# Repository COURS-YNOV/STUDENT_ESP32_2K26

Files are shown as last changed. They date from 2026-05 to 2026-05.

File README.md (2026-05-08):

# Projet ESP32 – Conception Électronique 2K26

## Contexte

Dans le cadre du projet de conception électronique, vous devez réaliser une carte de développement basée sur un **ESP32-PICO-D4**.

Le projet s’appuie sur un cahier des charges client fictif : **Ventec Systems**, entreprise spécialisée dans les AGV industriels. La carte doit permettre le monitoring d’un robot alimenté par une batterie 36V, avec mesure de courant, surveillance thermique, communication BLE et reprogrammation terrain.

Le cahier des charges complet ainsi que l’énoncé du projet sont disponibles dans le dossier :
```text
10_doc_ext/
```
Le projet Altium est situé dans :
```text
30_src/
```
Fichier projet principal :
```text
ESP32_Projet.PrjPcb
```

## Objectif du projet

Chaque équipe doit réaliser :

une analyse fonctionnelle du système ;
la sélection et l’étude des composants ;
la schématique de la carte ;
le routage PCB ;
les fichiers de fabrication ;
un rapport expliquant les choix techniques.

La carte doit respecter une taille maximale de :
```text
70 mm x 50 mm
```
Tous les composants doivent être placés uniquement sur la face TOP du PCB.

## Organisation des équipes

Le projet est réalisé en 5 équipes.

Chaque équipe doit travailler sur sa propre branche Git.

Format obligatoire du nom de branche :
```text
Equipe_1
Equipe_2
Equipe_3
Equipe_4
Equipe_5
```

## Structure du dépôt
```text
/10_doc_ext/
    CDC-VENTEC_SYSTEMS.pdf
    Enonce-Projet2k26_ESP32.pdf

/30_src/
    Projet Altium
    Librairies SCH_Lib / PCB_Lib
    PCB vierge
    Schématique vide
```

## Projet Altium

### Composants principaux

Les composants principaux imposés sont :

Microcontrôleur : ESP32-PICO-D4
Driver USB-UART : CP2104-F03-GM
Connecteur USB-C : USB4085-GF-A
Capteur de courant : INA237AIDGST

Des résistances, condensateurs, LEDs, connecteurs Grove / MikroBus, antenne, boutons reset / boot et autres composants seront également nécessaires.

### Contraintes principales

#### Alimentation

La carte doit pouvoir être alimentée par trois sources :

USB-C : 5V
BT : 3.7V à 10V
HT : jusqu’à 36V

La priorité d’alimentation doit être :
```text
USB > BT > HT
```
La gestion de priorité doit être réalisée matériellement, sans dépendre du firmware.

#### Mesures

La carte doit permettre :
- la mesure du courant sur la batterie 36V
- la surveillance de températures PCB
- la mesure de température ambiante
- l’ajout de capteurs via Grove / MikroBus

#### Communication

La carte doit intégrer :
- communication BLE
- USB-C pour reprogrammation et extraction des logs
- protection des lignes USB
- gestion de l’antenne BLE avec adaptation du plan de masse

#### IHM

La carte doit intégrer :
- LED verte de fonctionnement normal
- LED rouge d’alarme
- buzzer piloté par l’ESP32
- boutons reset et boot accessibles

## Règles de conception imposées
### Schématique

- Schématique en mils
- Titre, révision et nom du dessinateur attendus
- Paires différentielles clairement indiquées

### PCB

- PCB en mm
- Taille maximale : 70 mm x 50 mm
- Aucun composant sur la face Bottom
- Pas d’angles droits sur les pistes
- Arrivée des pistes au centre des pads
- Plan de masse obligatoire
- Plan d’alimentation recommandé
- Vias : pastille 0.85 mm, perçage 0.35 mm
- Sérigraphie : largeur 0.15 mm
- Impédance 90 Ω sur la ligne de reprogrammation UART
- Impédance 50 Ω sur la ligne RF
- Adaptation du plan de masse autour de l’antenne BLE

## Barème : Update en cours

## Workflow Git
1. Cloner le dépôt
```bash
git clone https://github.com/COURS-YNOV/STUDENT_ESP32_2K26.git
cd STUDENT_ESP32_2K26
```
2. Créer la branche de votre équipe
```bash
git checkout -b Equipe_X
```
Exemple : 
```bash
git checkout -b Equipe_1
```

3. Travailler uniquement sur votre branche

Ne travaillez jamais directement sur main.

4. Ajouter vos fichiers
```bash
git add .
```

5. Faire un commit
```bash
git commit -m "avancement projet ESP32"
```

6. Push les modifications sur votre branch
```bash
git push Equipe_X
```
## Rapport attendu

Le rapport doit contenir :
- Les analyses fonctionnelles (AF 1 & AF 2)
- L’explication des différents blocs schématiques
- Les choix techniques réalisés
- Deux problèmes rencontrés pendant le projet ainsi que leurs solutions
- Les captures ou éléments utiles à la compréhension du projet

Le rapport doit être rendu au format PDF.

## Conseils
- Lire entièrement le cahier des charges avant de commencer
- Répartir les tâches dans l’équipe
- Vérifier régulièrement le DRC
- Commiter souvent
- Générer les Gerbers même si le projet n’est pas terminé
- Utiliser la documentation et les tutoriels vus en cours

# Bon courage à tous !

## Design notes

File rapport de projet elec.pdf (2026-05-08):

Rapport de projet CDC – Ventec Systems Groupe KIMG
Irwin Ticon – Marine Jacolot – Guilhem Raffanel – Killian Guillemot

## Table des matières

# 1.Analyse fonctionnelle de niveau 1

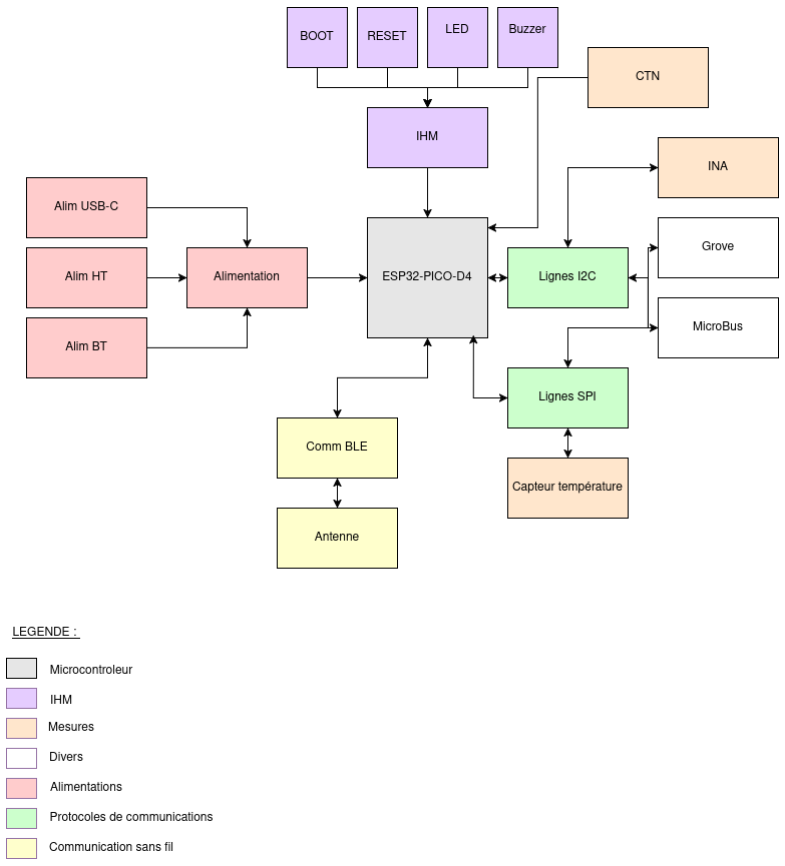
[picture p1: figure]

# 2.Analyse fonctionnelle de niveau 2

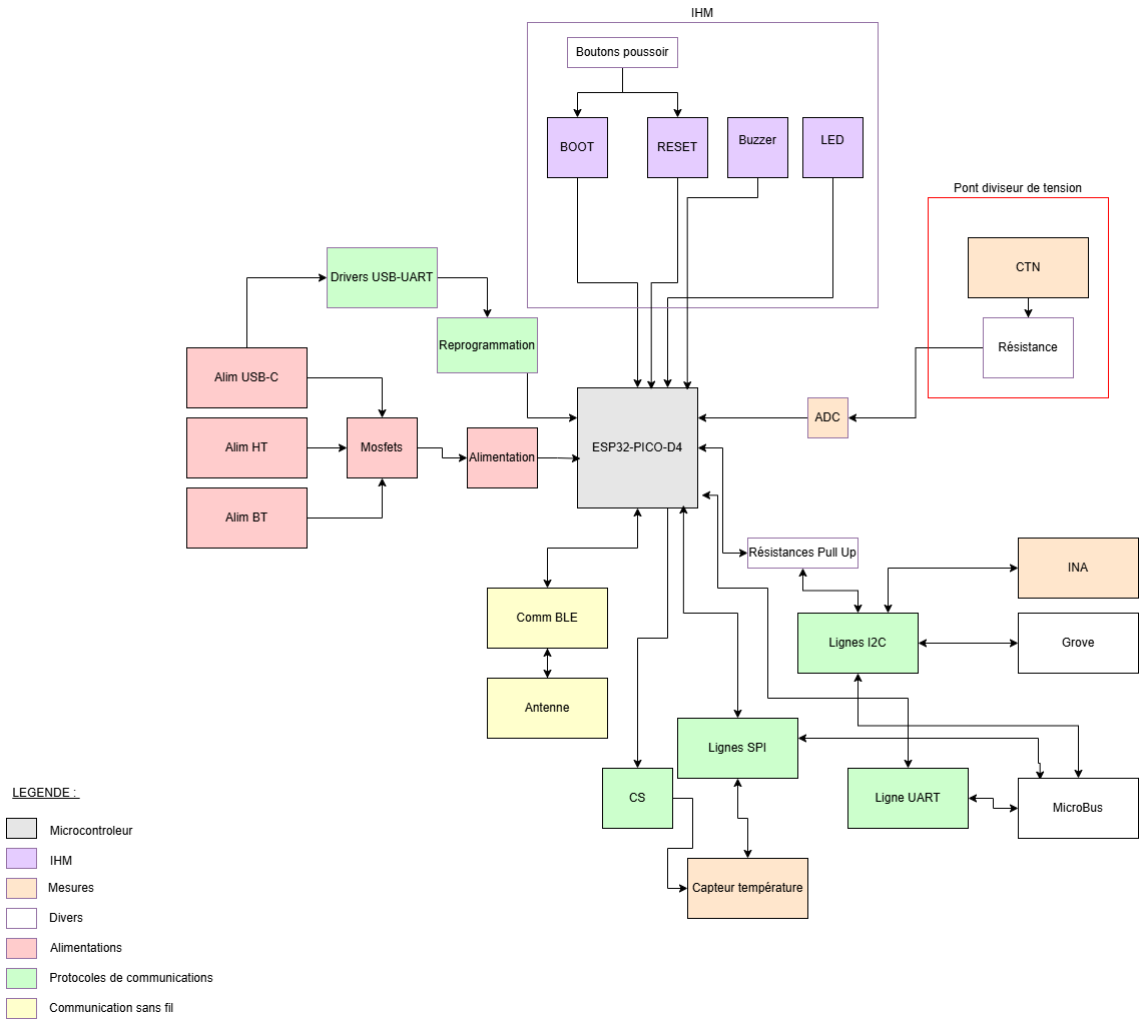
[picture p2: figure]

# 3.Schématiques

## a. Alimentations

### i. Alimentation HT

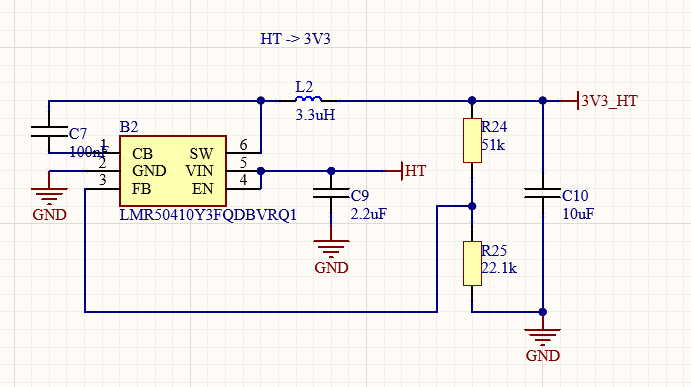
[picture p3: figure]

Le convertisseur LMR accepte des tensions d'entrée comprises entre -0,3 V et 38 V sur VIN, et entre 0 V et VIN+0,3 V sur EN, ce qui satisfait les exigences de notre application (plage 27 V–36 V). Le schéma a été conçu conformément à la configuration typique recommandée par le fabricant. Les résistances de polarisation R24 et R25 ont été dimensionnées selon les paramètres spécifiés dans la fiche technique du composant.

### ii. Alimentation 5V USB

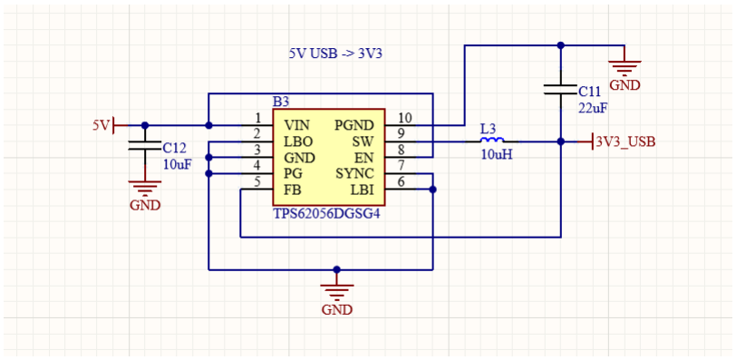
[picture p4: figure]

Le régulateur de tension TPS accepte des tensions d'entrée comprises entre 2,7 V et 10 V, ce qui satisfait notre besoin d'une tension de sortie stable de 5 V. Le schéma a été conçu
conformément à la configuration typique du fabricant.

Alimentation Basse Tension

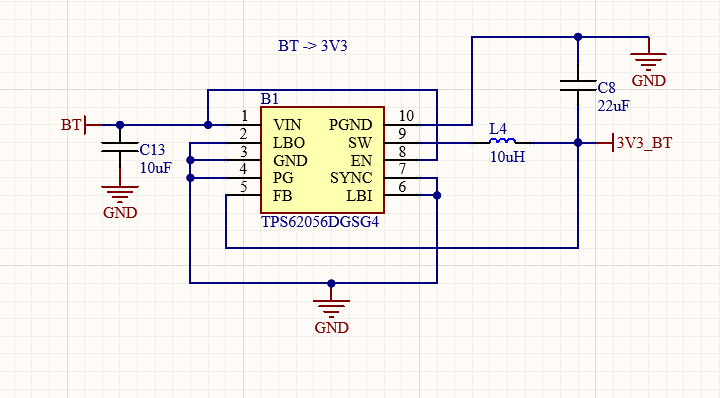
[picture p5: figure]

Le régulateur de tension TPS accepte des tensions d'entrée comprises entre 2,7 V et 10 V, couvrant ainsi la plage d'alimentation variable requise de 3,7 V à 10 V. Le schéma a été conçu conformément à la configuration typique recommandée par le fabricant.

### iii. Circuit de gestion de priorité d’alimentation

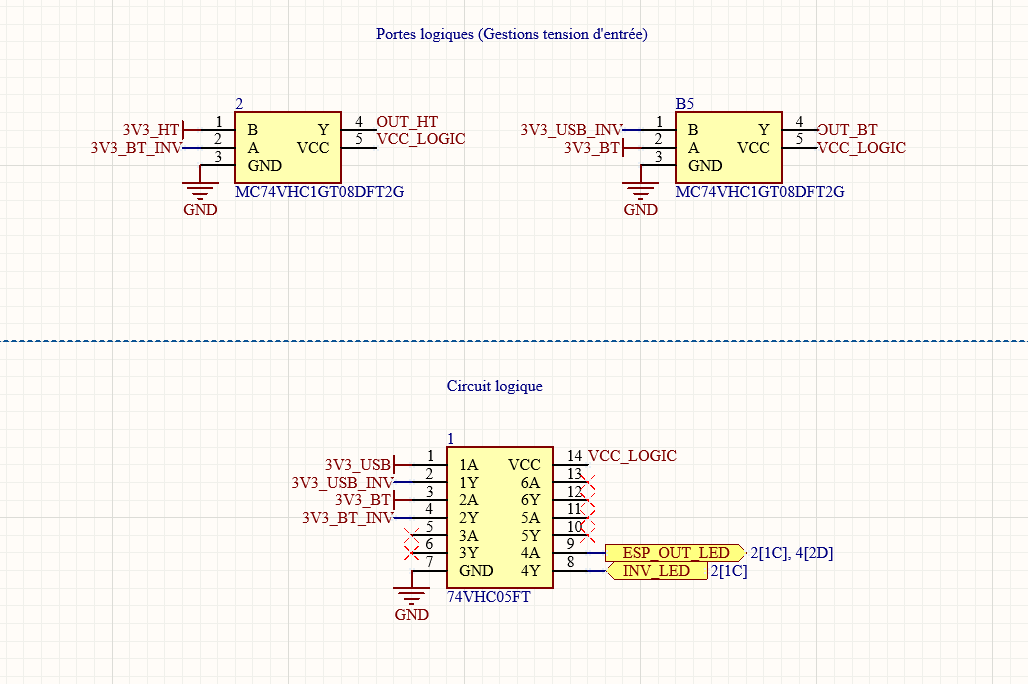
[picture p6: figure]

Le MC74 est une porte logique AND alimentée par VCC_LOGIC (3,3 V, provenant des régulateurs décrits précédemment). En sortie, il restitue la tension VIN lorsque les conditions logiques d'entrée sont satisfaites.

Le 74VH est un circuit intégré contenant plusieurs portes logiques NOT, également alimenté par VCC_LOGIC (3,3 V). Il fournit en sortie la tension VIN inversée selon la logique appliquée en entrée.

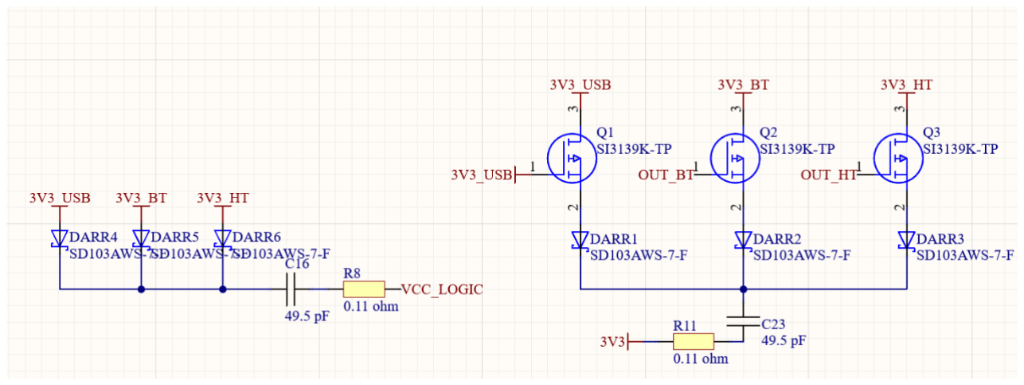
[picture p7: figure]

Des transistors MOSFET canal P ont été sélectionnés comme interrupteurs commandés par les signaux logiques. La section gauche du schéma assure l'alimentation des portes logiques, avec protection par diodes. L'ensemble intègre des condensateurs de découplage et des résistances de charge pour garantir la stabilité et les transitions correctes.

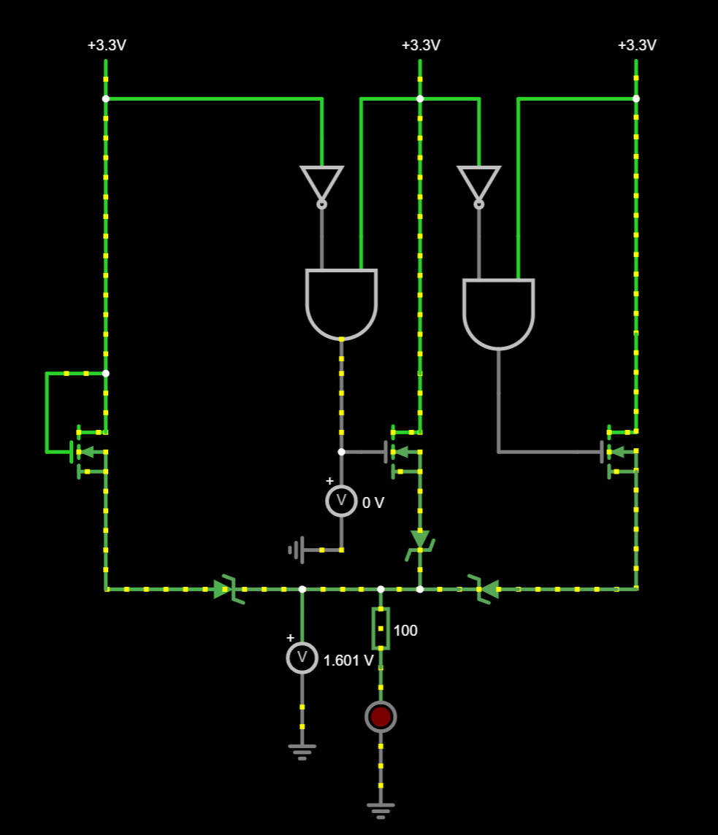
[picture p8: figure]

Le schéma ci-dessus est une simulation sur le logiciel Falstad montrant le montage de gestion de priorité d’alimentation.

## b. IHM

### i. Buzzer

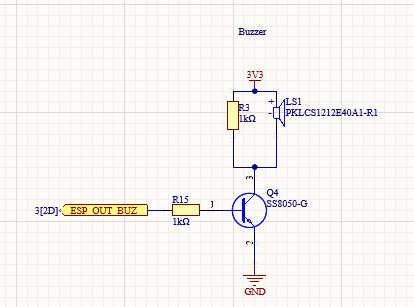
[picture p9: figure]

Choix de composant :
Selon L’EXF-26 nous avons modifié l’usage typique du PKLCS en retirant les portes logiques et en le connectant directement à l’ESP pour nous permettre de piloter le PKLCS depuis l’ESP directement
Ce circuit permet un pilotage fiable d’un buzzer via un pin sortie, en utilisant un transistor comme interface de puissance.
La schématique a été assemblé selon l’usage typique du PKLCS

### ii. LED

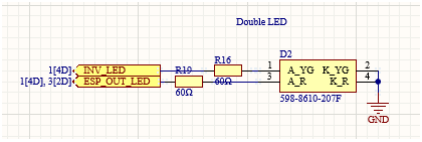
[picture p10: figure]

Choix des composants :
Ce montage permet un pilotage simple et sécurisé d’une double LED à partir d’une sortie microcontrôleur, avec limitation de courant intégrée et possibilité d’indication visuelle
Les signaux de commande INV_LED et ESP_OUT_LED permettent de piloter l’allumage de la LED via un pin sortie du microcontrôleur (ESP) et un inverseur logique.
Les valeurs de 60 Ω ont été choisie pour obtenir un courant maîtrisé dans la LED (~4 à 11 mA selon la couleur)

## c. ESP

### i. Partie A

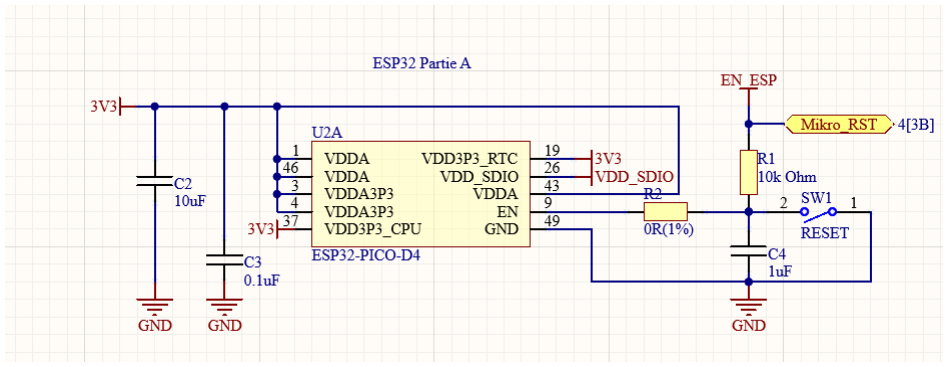
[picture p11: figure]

Choix des composants :
Ce montage correspond à l’alimentation et au démarrage de l’ESP32-PICO-D4. Il permet d’obtenir une alimentation stable en 3V3 tout en assurant un reset correct du microcontrôleur. Les condensateurs C2 et C3 ont été placés en découplage sur l’alimentation afin de filtrer les parasites et de stabiliser la tension fournie à l’ESP32.
La résistance R1 maintient la ligne EN_ESP à l’état haut en fonctionnement normal. Elle joue donc le rôle de pull-up sur l’entrée de reset.
Le bouton SW1 permet de forcer un RESET manuel du microcontrôleur en mettant la ligne de commande à la masse lorsqu’il est actionné.
Le condensateur C4 améliore la mise sous tension et le comportement du reset en filtrant les variations trop rapides sur la ligne EN.
La résistance R2 sert de liaison directe entre la broche EN de l’ESP32 et le signal de commande, tout en offrant une solution simple de modification ou d’adaptation du circuit si nécessaire. L’ensemble du schéma respecte ainsi une structure classique de mise sous tension et de réinitialisation pour un ESP32, avec une alimentation filtrée et un circuit de reset fiable.

### ii. Partie B

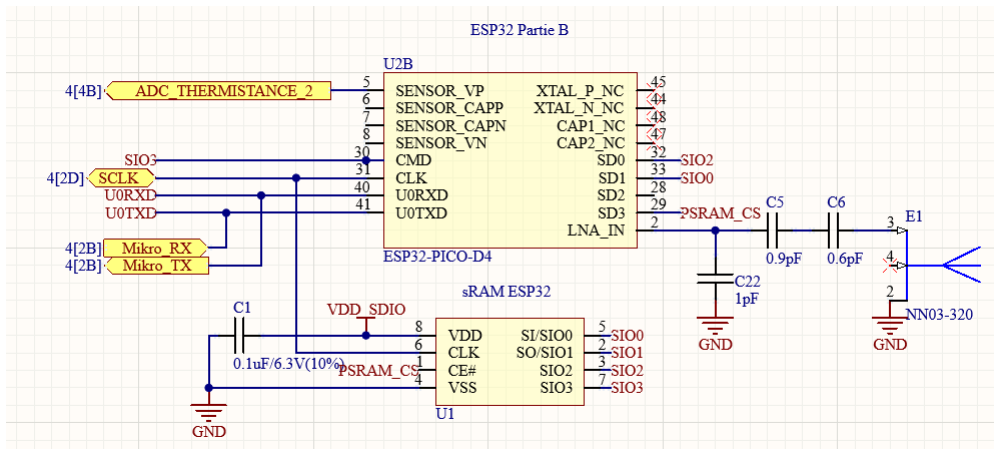
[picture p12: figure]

Choix des composants :
Ce montage correspond à l'interface mémoire et RF de l'ESP32-PICO-D4. Il étend la capacité mémoire du microcontrôleur et assure une connexion radio fiable.
Le condensateur C1 est placé en découplage sur le rail VDD_SDIO. Il filtre les parasites et stabilise la tension fournie à la SRAM.
La mémoire U1 est une SRAM externe connectée à l'ESP32 via un bus SPI quad. La broche CE# est pilotée par le signal PSRAM_CS pour activer ou désactiver la communication avec la mémoire. Elle permet d'augmenter la mémoire disponible pour l'exécution du programme. Les condensateurs C5, C6 et C22 forment un réseau d'adaptation d'impédance entre la sortie RF de l'ESP32 et l'antenne E1. Leurs valeurs de 0,9 pF, 0,6 pF et 1 pF ont été choisies pour minimiser les pertes du signal radio.
L'antenne E1 est une antenne compacte de type chip antenna. Elle a été choisie pour son encombrement réduit et ses bonnes performances sur la bande Wi-Fi de l'ESP32.
L'ensemble du schéma respecte une structure classique d'extension mémoire et de connexion RF pour un ESP32, avec une mémoire filtrée et un circuit d'adaptation d'antenne soigné.

### iii. Partie C

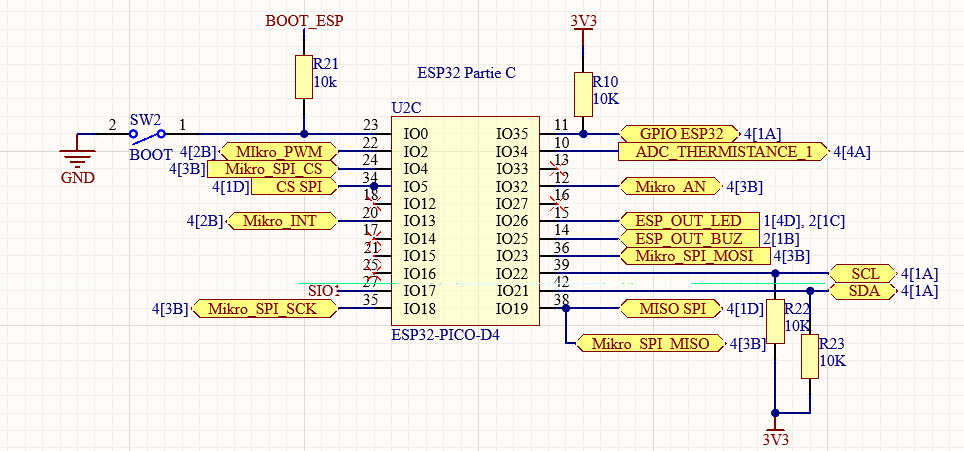
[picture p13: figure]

Choix des composants :
Ce montage correspond à l'affectation des entrées/sorties de l'ESP32-PICO-D4. Il regroupe les signaux de contrôle, de communication et de mesure du microcontrôleur.
La résistance R21 est placée en pull-up sur la ligne BOOT_ESP. Elle maintient la broche IO0 à l'état haut au démarrage. Le bouton SW2 permet de forcer le mode bootloader en tirant cette ligne à la masse.
Les broches IO4, IO5 et IO18 gèrent les signaux du bus SPI. Elles assurent la sélection des périphériques et l'horloge vers les modules externes.
La broche IO19 reçoit les données en provenance des périphériques SPI via le signal MISO_SPI. Les broches IO34 et IO35 permettent des lectures analogiques et numériques pour la thermistance et le GPIO vers les connecteurs externes.
Les broches IO25 et IO26 pilotent la LED et le buzzer depuis le microcontrôleur via les signaux ESP_OUT_LED et ESP_OUT_BUZ.
Les résistances R22 et R23 sont placées en pull-up à 10K sur les lignes SCL et SDA. Elles assurent un niveau haut stable sur le bus I2C alimenté en 3V3.
L'ensemble du schéma respecte une structure classique d'affectation des broches d'un ESP32, avec une séparation claire entre les signaux SPI, I2C, analogiques et de contrôle.

### iv. Prog ESP32

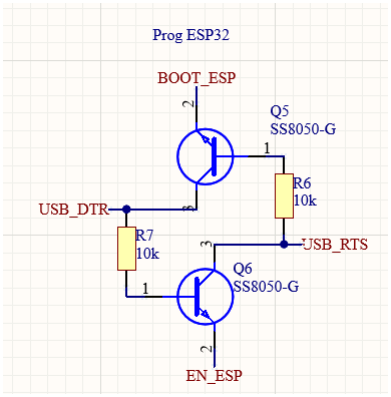
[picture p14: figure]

Choix des composants :
Ce montage correspond au circuit de programmation automatique de l'ESP32. Il permet de contrôler les lignes BOOT_ESP et EN_ESP depuis l'interface USB sans intervention manuelle. Les transistors Q5 et Q6 sont des SS8050-G utilisés en commutation. Ils sont pilotés par les signaux USB_DTR et USB_RTS pour contrôler respectivement les lignes BOOT_ESP et EN_ESP. Les résistances R6 et R7 sont placées en pull-up à 10K sur les bases des transistors. Elles assurent un état stable sur les lignes de commande lorsqu'aucun signal n'est appliqué. L'ensemble du schéma permet une programmation automatique de l'ESP32 via l'USB, sans avoir à appuyer manuellement sur les boutons BOOT et RESET.

### v. USB

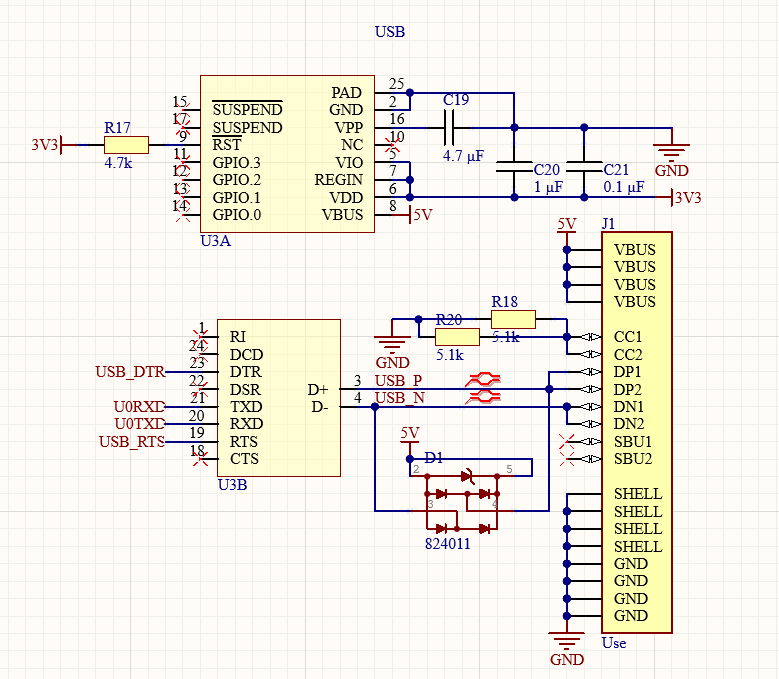
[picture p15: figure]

Choix des composants :
Ce montage correspond à l'interface USB du système. Il assure la communication entre le port USB-C et l'ESP32 via un convertisseur USB-UART.
U3A est le contrôleur USB et U3B est le convertisseur USB-UART. Ils travaillent ensemble pour assurer la liaison série entre l'USB et l'ESP32 via les signaux U0RXD, U0TXD, USB_DTR et USB_RTS.
La résistance R17 est placée en pull-up sur la ligne RST de U3A. Elle maintient le contrôleur en fonctionnement normal.
Les résistances R18 et R20 sont placées sur les lignes CC1 et CC2 du connecteur USB-C. Elles permettent la détection du rôle de l'appareil sur le bus USB-C.
Le composant D1 est placé sur les lignes USB_P et USB_N. Il protège le bus de données contre les surtensions ESD.
Les condensateurs C19, C20 et C21 sont placés en découplage sur les rails d'alimentation. Ils filtrent les parasites à différentes fréquences.
L'ensemble du schéma respecte une structure classique d'interface USB-C vers UART, avec une protection ESD et un découplage soigné.

### d. Capteurs i. INA

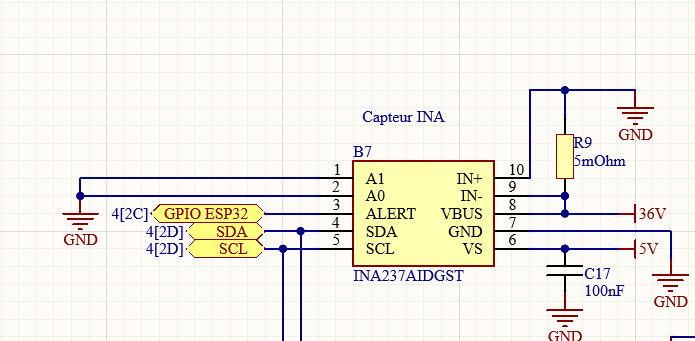
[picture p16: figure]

Le capteur INA237AIDGST (référence B7) est branché selon l'usage standard défini par la fiche technique, avec une résistance de shunt permettant la mesure du courant et la surveillance des tensions d'alimentation 36V et 5V via interface I2C.
La résistance de shunt R9 (5 mΩ) convertit le courant mesuré en tension exploitable par le capteur INA237AIDGST. Son dimensionnement s'effectue en fonction de la plage ADC sélectionnée (registre ADCRANGE). Pour ADCRANGE = 0, la plage de mesure est 163.84 mV (pleine échelle)

En supposant la configuration en ADCRANGE = 0 avec une plage de 163.84 mV et un courant maximal de 35 A, la résistance de shunt maximale se calcule par :

RSHUNT_MAX =

VSENSE_MAX

IMAX

=

163.84 mV
35 A

= 4.68 mΩ

La résistance de shunt de 5 mΩ respecte légèrement la limite théorique, offrant une marge minime, ce qui est acceptable dans notre cas.

### ii. Thermistances

### iii. Capteur de température

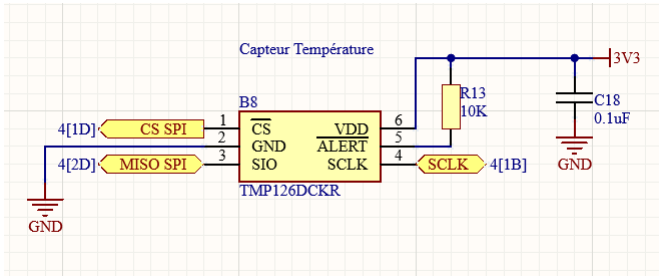
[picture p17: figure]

Le capteur B8 est un TMP branché selon l'usage type donné dans la fiche technique. La résolution de la mesure est donnée par :
LSB = 0,0625 °C / bit
Ce qui donne une plage de mesure de -40°C à +125°C avec une précision de ±0,5°C.
La résistance R13 est placée en pull-up à 10K sur la broche ALERT. Elle maintient la ligne à l'état haut en fonctionnement normal.
Le condensateur C18 est placé en découplage sur le rail 3V3. Il filtre les parasites sur l'alimentation du capteur.

## e. Connecteurs

### i. MikroBus

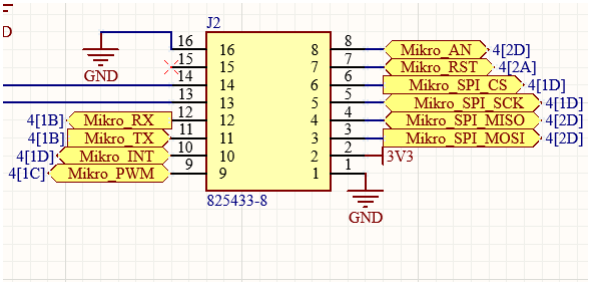
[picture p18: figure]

Le connecteur MikroBus fournit une interface multi-protocoles standardisée par Mikroe, combinant UART, SPI et signaux de contrôle (PWM, interruption, réinitialisation) pour une intégration modulaire et flexible des cartes d'extension.

### ii. Groove

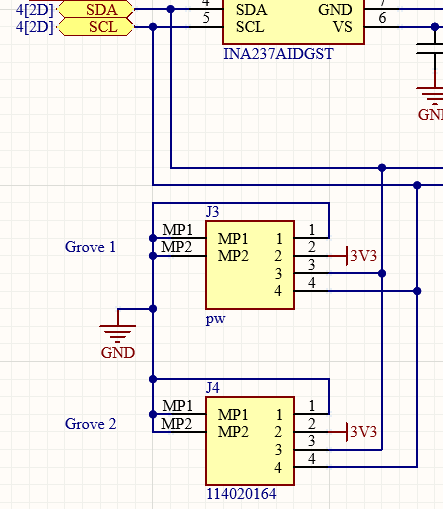
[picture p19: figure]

Configuration I2C du connecteur Groove pour deux modules capteurs (Grove 1 et Grove 2) alimentés via le bus d'alimentation commun, selon le schéma d'application standard défini par le fabricant.

# 4.Problèmes rencontrés

## a. Gestion des priorités d'alimentation dans EXF-3

Problème rencontré :
Lors de la phase de conception de la gestion des priorités d'alimentation, une difficulté a été identifiée avec l'approche initiale.
L'utilisation d'ensembles de MOSFETs pour respecter l'ordre de priorité requis dans EXF-3 s'est avérée sous-optimale. Cette configuration impliquait des modifications des tensions des alimentations, ce qui n'était pas satisfaisant.

Solution adoptée :
La gestion a été confiée à des circuits logiques pilotant les MOSFETs, permettant de bloquer ou d'autoriser sélectivement les alimentations.
Le choix de l'alimentation est ainsi dissocié de sa distribution proprement dite : les portes logiques sélectionnent l'entrée active (avec une capacité en courant limitée, inadaptée à la charge finale), tandis que les MOSFETs assurent la commutation haute intensité.

## b. Sélection de l'antenne pour la communication BLE

Problème rencontré
Lors de la recherche de composants pour l'antenne dédiée à la communication BLE, il a été constaté que le modèle initialement sélectionné n'était plus produit.

Solution adoptée
Un modèle alternatif, toujours en production et conforme aux exigences du cahier des charges, a été retenu.

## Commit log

2026-05-08 feat: initial ESP32 project setup for students
    [ESP32_Projet.PrjPcb, PCB1.PcbDoc, PCBLibrary.PcbLib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]
2026-05-08 Add files and project
    [Alim_Schematic.SchDoc, Capteurs_Schematic.SchDoc, ESP32_Projet.PrjPcb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]
